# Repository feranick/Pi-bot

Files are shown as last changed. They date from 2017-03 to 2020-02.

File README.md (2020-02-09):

# Pi-bot (piRC)
**Raspberry Pi Remote-controlled/autonomous cars**. Different approaches for control and driving are available:
- Fully autonomous through deep learning neural networks 
- Driving aid, pseudo-automated (tries to avoid obstacles)
- Manual controlled via HTML interface

## Hardware
- robot: RC car with one motor for power, one motor for steering.
- controller: [Raspberry Pi 3 B](https://www.raspberrypi.org/products/raspberry-pi-3-model-b/) or [3 B+](https://www.raspberrypi.org/products/raspberry-pi-3-model-b-plus/). [Raspberry PI zero w](https://www.raspberrypi.org/products/pi-zero-w/)  can be used only with SKLearn and no camera.
- ADC controller: 4 channel 16bit, [ADS1115](http://www.ti.com/lit/ds/symlink/ads1115.pdf) (Op. Voltage: 3.3V)
- Accelerometer: XYZ, [ADXL345](http://www.analog.com/en/products/mems/accelerometers/adxl345.html) (Op. Voltage: 3.3V)
- Stepper motor controller: Adafruit [TB6612](https://learn.adafruit.com/adafruit-tb6612-h-bridge-dc-stepper-motor-driver-breakout/overview), 1.2A DC (Op. Voltage: 3.3V or 5V)
- Sensing the motor status requires a 1.5MOhm resistor to from the power motor leads to the ADS1115. 
- Sonars: 4 [HC-SR04](http://www.micropik.com/PDF/HCSR04.pdf) (left, right, center, back); (Op. Voltage: 5V)
  Warning: the output operating voltage is 5V, while RPi accepts only up to 3.3V, so you need a voltage divider.
- Radar (support is upcoming): 1 microwave Doppler Radar [HB100](https://www.tindie.com/products/limpkin/hb100-doppler-speed-sensor-arduino-compatible/)
- [Raspberry Pi Camera Module](https://www.raspberrypi.org/products/camera-module-v2/)
- Optional: [Google Coral EdgeTPU](https://coral.ai/docs/accelerator/get-started/) for on device efficient inference is supported. Please refer to the product page for installation.

- Deprecated IR sensors:
    - 2 front left side break beam sensors [3mm LEDs](https://www.adafruit.com/products/2167)
    - 1 front [GP2Y0A21YK0F](http://www.sharp-world.com/products/device/lineup/data/pdf/datasheet/gp2y0a21yk_e.pdf) Sharp IR Analog Distance Sensor 10-80cm

## Requirements
Since it uses Python3, it requires the following packages

    sudo apt-get install python3-rpi.gpio python3-dev python3-pip libopenjp2-7 libatlas-base-dev libtiff5 python3-picamera libhdf5-serial-dev libhdf5-dev

You would then need to install two libraries for the ADC (ADS1115) and accelerometer (ADXL345)

    sudo pip3 install adafruit-adxl345 adafruit-ads1x15 Pillow configparser wheel

Machine learing is carried out using Sklearn by default, which needs the following packages:

    sudo pip3 install numpy sklearn 
    
Alternatively and only when used with a Raspberry Pi 3, TensorFlow can be used instead. To install: 

    sudo pip3 install tensorflow tflite-runtime

## Installation
When inside teh folder `Pi-bot/piRC` from the command line:

    python3 setup.bdist_wheel
    sudo pip3 install --upgrade dist/pirc-xxxxxxxx-py3-none-any.whl  
    
You can also run the software directly from the folder (although it is discouraged).
    
- Upon booting Raspbian, the motors may not be responsive due to some GPIO channels not being properly initialized. Use (`piRC/other/pirc_init.py`) to initialize them.

## Usage
### piRC (deep learning neural networks)
All required parameters for ML and for the RC are included into `pirc.ini` which is included in Pi-bot/pirc. If not present, a default file is created upon launching the software.
 
This software (piRC/machine_learning/piRC_ML.py) is designed to accomplish three main tasks
- **Collection mode (CM)** Collect sensor data and save it into what will be a training file. When the software is operated with CM, the user is supposed to operate the RC in fully manual mode (i.e. using the original remote control. You can stop the collection by exiting with CTRL+C. The result is a file (`Training_splrcbxyz.txt`) with sensor readings that are ready for machine training. Examples are provided in `piRC/piRC_ML/Training` (it is strongly recommended to create your own). CM mode runs using this command:

    `pirc -c`

- **Training mode (TM)** Using the training file (for example `Training_splrcbxyz.txt`), a neural network training model is created and saved with the extension `.nnModelC.pkl`. Training can be conducted in the Rpi within the RC car itself, or in any other computer running python and related libraries. This usually is much much faster. TM mode runs using this command:

    `pirc -t <training file>`

- **Running mode (RM)** Once the training is completed, you can run run the inference mode (which uses sensor data acquired in real time to infer steering and power) and ultimately the RC car itself through this command

    `pirc -r Training_splrcbxyz.txt`

Both Classification (default) and Regression can be used.

A few notes on RM:
- If training model is not available, one is created at launch time.
- a bash script is provided (`piRC/machine_learning/syncTraining/syncTFile.sh`) to allow the transfer of the training file to a separate computer, run the training in that computer and retrieve the model for usage in the piRC.
- The training file can be improved while in RM by adding real time sensor data to it (the flag `saveNewTrainingData` needs to be set to True). This is useful as a new training model can be created on the fly (using the bash script as per the previous point). piRC_ML.py can be set to periorically reload (default is 15 seconds, change using `syncTimeLimit`) the training model without relaunching the script (the flag `syncTrainModel` needs to be set to True).
- Two Machine learning methodsare available: using the MultiPerceptron Classifier (`MLPClassifier`, recommended) or Regressor (`MLPRegressor`, highly experimental and not recommended). 
- Two operation modes are available, and can be enabled using the flab `runFullAuto`:
    - Partial Auto: piRC will only respond to the sensor data, but it will no proactively "drive forward" if it has no reason for it. You need to use manual commands to help it. 
    - Full Auto: piRC will proactively drive forward if it has been standing still for a given amount of time. 

### Manual control through web interface (discontinued)
piRC can be controlled using a web interface. Communication between PHP and python is done: 
- via shared file (piRC_file). Auto and manual control take place within the same python script
- via shell (piRC_nofile): Auto control is automated, in the background. Manual control is done via python script when the user 
is calling for an action.

### Additional utilities
- `pirc_init`: Initialize sensors and GPIO ports for full use with remote control.

### Installation (deprecated)
To be working properly, a library file piRC_lib.py needs to be copied inside each of the folders:
- piRC_file
- piRC_nofile
- piRC_ML
- Upon booting Raspbian, the motors may not be responsive due to some GPIO channels not being properly initialized. Use (piRC/other/pirc_init.py) to initialize them.

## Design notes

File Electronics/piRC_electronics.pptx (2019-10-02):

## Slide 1

RPi provides full power

| RCBR | RCBL | | RCBB | RCBF
RCMS - | RCMS+ | | | RCMP- | RCM+

RCB-
RCB+

Motor
Controller

| | | GPIO 14 (12) | GPIO 15 (10) | GPIO 18 (12) | | GPIO 17 (11) | GPIO 27 (13) | GPIO 22 (15)

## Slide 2

RC provides power to Motor controller

| RCBR | RCBL | | RCBB | RCBF
RCMS - | RCMS+ | | | RCMP- | RCM+

RC battery -
RCB-
RCB+
RC battery +

Motor
Controller

| | | GPIO 14 (12) | GPIO 15 (10) | GPIO 18 (12) | | GPIO 17 (11) | GPIO 27 (13) | GPIO 22 (15)

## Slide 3

| GPIO (4) 5V | GPIO (6) GND | | SONAR 5V | SONAR GND

ADC

GPIO (1) 3.3V | GPIO (3) SDA1 | GPIO (5) SCL1 | | GPIO (9) GND

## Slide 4

VCC – RADAR (White)
GND – RADAR (Green)

GPIO8 (24) SPI CE0 (Orange/Yellow)

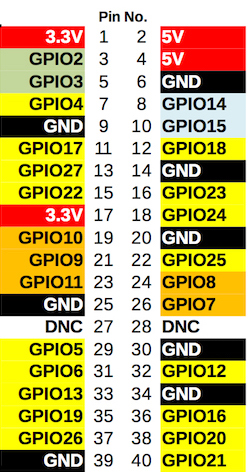
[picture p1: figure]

Example: GPIO 14 (8): GPIO14, pin number 8

RCB = RC Car Main Board
RCMP = RC Car Power Motor
RCMS = RC Car Steer Motor

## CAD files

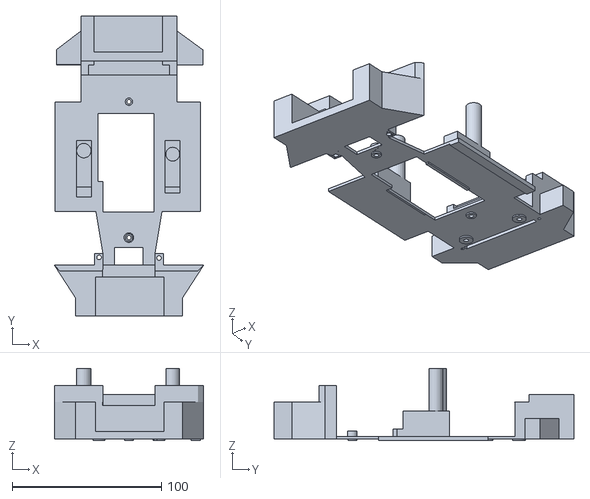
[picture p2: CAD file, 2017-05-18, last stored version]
Sketchup/Chassis_PiRC_11.stl
100.0 x 200.9 x 48.4

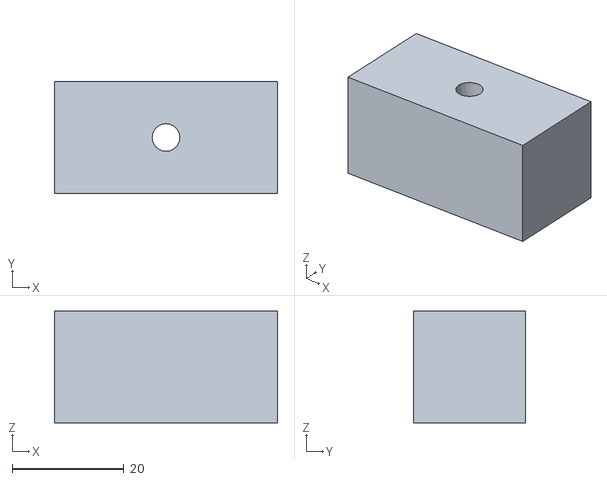
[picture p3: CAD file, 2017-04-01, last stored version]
Sketchup/IR-sensors-holder_2.stl
40.0 x 20.0 x 20.0

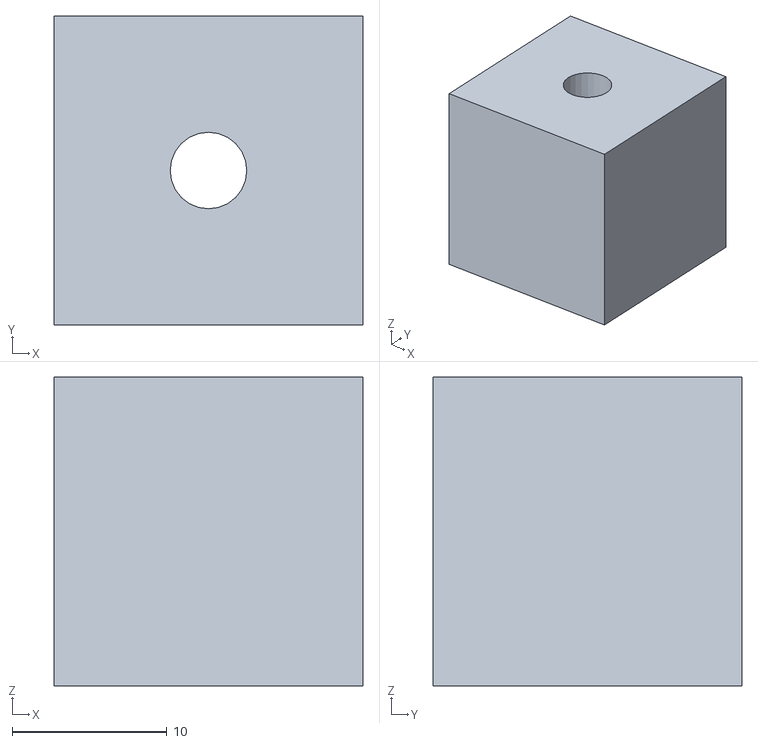
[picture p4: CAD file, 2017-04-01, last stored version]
Sketchup/IR-sensors-holder.stl
20.0 x 20.0 x 20.0

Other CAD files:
Sketchup/Chassis_PiRC_11.skp
Sketchup/IR-sensors-holder.skp
Sketchup/IR-sensors-holder_2.skp

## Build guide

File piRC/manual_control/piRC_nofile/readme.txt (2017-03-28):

pirc_auto.py: controls sensors and object avoidance. It should run in the background.
pirc_manual.py: called from PHP, runs only when needed by user intervention.

In order to have the required permission:

- add the following to the sudoers (sudo visudo):
www-data ALL = NOPASSWD:  /var/www/html/pirc_nofile/piRC_manual.py, /usr/bin/python3

You may be able to speed up launching the python script by compiling it first:

python3 -m compileall ./

In this case, you need to change the proper line in the index.php file.

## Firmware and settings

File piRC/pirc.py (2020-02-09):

#!/usr/bin/env python3
# -*- coding: utf-8 -*-
'''
**********************************************************
* PiRC - Self-driving RC car via Machine Learning
* version: 20200209a
* By: Nicola Ferralis <feranick@hotmail.com>
***********************************************************
'''
print(__doc__)

import numpy as np
import sys, os.path, os, getopt, glob, csv, joblib, configparser
import h5py, pickle
from time import sleep, time
from os.path import exists, splitext
from os import rename
from datetime import datetime, date

from sklearn.neural_network import MLPClassifier, MLPRegressor
from sklearn.preprocessing import StandardScaler
#import libpirc #Comment this out for debug mode.

#***************************************************
# This is needed for installation through pip
#***************************************************
def pirc():
    main()

#************************************
# Parameters
#************************************
class Conf():
    def __init__(self):
        confFileName = "pirc.ini"
        self.configFile = os.getcwd()+"/"+confFileName
        self.conf = configparser.ConfigParser()
        self.conf.optionxform = str
        self.tf_directory = "TF_MLP"
        if os.path.isfile(self.configFile) is False:
            print(" Configuration file: \""+confFileName+"\" does not exist: Creating one.\n")
            self.createConfig()
        self.readConfig(self.configFile)
        
        if self.useCamera == True:
            self.filename = 'Training_splrcbxyzvCam.txt'
            self.camStr = "ON"
        else:
            self.filename = 'Training_splrcbxyzv.txt'
            self.camStr = "OFF"
            
        if self.ML_framework == "SKLearn":
            self.runNN_SK = True
            self.runNN_TF = False
        if self.ML_framework == "TF":
            self.runNN_SK = False
            self.runNN_TF = True
    
        self.scaler = StandardScaler()
        self.scalFileExt = '_scaler.pkl'
        self.mlp = MultiClassReductor()
        
        if not self.debug:
            importModule("libpirc")
            
        self.edgeTPUSharedLib = "libedgetpu.so.1"
            
    def pircDef(self):
        self.conf['Parameters'] = {
            'timeDelay' : .25,
            'runFullAuto' : True,
            'useCamera' : True,
            'nnAlwaysRetrain': True,
            'syncTimeLimit': 20, # time in seconds for NN model synchronization
            'syncTrainModel': False,
            'saveNewTrainingData': True,
            'ML_framework': 'SKLearn',     # Use either: SKLearn (for scikit-learn) or TF (for TensorFlow)
            'useRegressor': False,
            'HL': [270,170,70,10],
            'l2' : 1e-5,
            'epochs' : 200,
            }
            
        self.conf['SKLearn'] = {
            'nnSolver': 'lbfgs',  #Solver for NN lbfgs preferred for small datasets. Alternatives: 'adam' or 'sgd'
            }
            
        self.conf['TF'] = {
            'l_rate' : 0.001,
            'l_rdecay' : 1e-4,
            'drop' : 0,
            'cv_split' : 0.01,
            'fullSizeBatch' : True,
            'batch_size' : 64,
            }
            
        self.conf['System'] = {
            'makeQuantizedTFlite' : False,
            'useTFlitePred' : False,
            'TFliteRuntime' : False,
            'runCoralEdge' : False,
            'debug': False, # do not activate sensors or motors in debug mode
            #'setMaxMem' : False,   # TensorFlow 2.0
            #'maxMem' : 4096,       # TensorFlow 2.0
            }
            

    def readConfig(self,configFile):
        try:
            self.conf.read(configFile)
            self.pircDef = self.conf['Parameters']
            self.sklearnDef = self.conf['SKLearn']
            self.TF = self.conf['TF']
            self.sysDef = self.conf['System']
            
            self.timeDelay = self.conf.getfloat('Parameters','timeDelay')
            self.runFullAuto = self.conf.getboolean('Parameters','runFullAuto')
            self.useCamera = self.conf.getboolean('Parameters','useCamera')
            self.nnAlwaysRetrain = self.conf.getboolean('Parameters','nnAlwaysRetrain')
            self.syncTimeLimit = self.conf.getint('Parameters','syncTimeLimit')
            self.syncTrainModel = self.conf.getboolean('Parameters','syncTrainModel')
            self.saveNewTrainingData = self.conf.getboolean('Parameters','saveNewTrainingData')
            self.ML_framework = self.conf.get('Parameters','ML_framework')
            self.useRegressor = self.conf.getboolean('Parameters','useRegressor')
            self.HL = eval(self.pircDef['HL'])
            self.l2 = self.conf.getfloat('Parameters','l2')
            self.epochs = self.conf.getint('Parameters','epochs')
            
            self.nnSolver = self.conf.get('SKLearn','nnSolver')
            
            self.l_rate = self.conf.getfloat('TF','l_rate')
            self.l_rdecay = self.conf.getfloat('TF','l_rdecay')
            self.drop = self.conf.getfloat('TF','drop')
            self.cv_split = self.conf.getfloat('TF','cv_split')
            self.fullSizeBatch = self.conf.getboolean('TF','fullSizeBatch')
            self.batch_size = self.conf.getint('TF','batch_size')
            
            self.makeQuantizedTFlite = self.conf.getboolean('System','makeQuantizedTFlite')
            self.useTFlitePred = self.conf.getboolean('System','useTFlitePred')
            self.TFliteRuntime = self.conf.getboolean('System','TFliteRuntime')
            self.runCoralEdge = self.conf.getboolean('System','runCoralEdge')
            self.debug = self.conf.getboolean('System','debug')
            
        except:
            print(" Error in reading configuration file. Please check it\n")

    # Create configuration file
    def createConfig(self):
        try:
            self.pircDef()
            with open(self.configFile, 'w') as configfile:
                self.conf.write(configfile)
        except:
            print("Error in creating configuration file")

#**********************************************
''' MultiClassReductor '''
#**********************************************
class MultiClassReductor():
    def __self__(self):
        self.name = name
    
    totalClass = [[-1,-1],[-1,0],[-1,1],[0,-1],[0,0],[0,1],[1,-1],[1,0],[1,1]]
    
    def transform(self,y):
        Cl = np.zeros(y.shape[0])
        for j in range(len(y)):
            Cl[j] = self.totalClass.index(np.array(y[j]).tolist())
        return Cl
    
    def inverse_transform(self,a):
        return self.totalClass[int(a)]
        
    def classes_(self):
        return self.totalClass
        
    def num_classes_(self):
        return len(self.totalClass)


#**********************************************
''' Main '''
#**********************************************
def main():
    params = Conf()
    try:
        opts, args = getopt.getopt(sys.argv[1:], "rtch:", ["run", "train", "collect", "help"])
    except:
        usage()
        sys.exit(2)
    
    if opts == []:
        usage()
        sys.exit(2)

    for o, a in opts:
        if o in ("-r" , "--run"):
            try:
                runAuto(sys.argv[2],params.runFullAuto)
            except:
                exitProg()

        if o in ("-t" , "--train"):
            try:
                runTrain(sys.argv[2])
            except:
                exitProg()

        if o in ("-c" , "--collect"):
            try:
                writeTrainFile()
            except:
                exitProg()

#*************************************************
''' seletMLFramework '''
''' Select and initialize appropriate framework '''
#*************************************************
def selectMLFramework(sensors, Cl, trainFileRoot):
    params = Conf()
    printParams()
    if params.runNN_SK:
        #print(" Using SKLearn")
        model = runNN_SK(sensors, Cl, trainFileRoot)
    if params.runNN_TF:
        if params.TFliteRuntime:
            import tflite_runtime.interpreter as tflite
            # model here is intended as interpreter
            if params.runCoralEdge:
                model = tflite.Interpreter(model_path=os.path.splitext(fileTrainingData(trainFileRoot, True))[0]+'_edgetpu.tflite',
                experimental_delegates=[tflite.load_delegate(params.edgeTPUSharedLib,{})])
            else:
                model = tflite.Interpreter(model_path=os.path.splitext(fileTrainingData(trainFileRoot, True))[0]+'.tflite')
            model.allocate_tensors()
        else:
            import tensorflow as tf
            if params.useTFlitePred:
                # model here is intended as interpreter
                model = tf.lite.Interpreter(model_path=os.path.splitext(fileTrainingData(trainFileRoot, True))[0]+'.tflite')
                model.allocate_tensors()
            else:
                model = tf.keras.models.load_model(fileTrainingData(trainFileRoot, True))

    return model

#*************************************************
''' runAuto '''
''' Use ML models to predict steer and power '''
#*************************************************
def runAuto(trainFile, type):
    params = Conf()
    trainFileRoot = os.path.splitext(trainFile)[0]
    Cl, sensors = readTrainFile(trainFile)
    model = selectMLFramework(sensors, Cl, trainFileRoot)
    scal = pickle.loads(open(trainFileRoot+params.scalFileExt, "rb").read())
    fullStop(False)
    syncTime = time()
    while True:
        if time() - syncTime > params.syncTimeLimit and params.syncTrainModel == True:
            print(" Reloading NN model...")
            model = selectMLFramework(sensors, Cl, trainFileRoot)
            print(" Synchronizing NN model...\n")
            os.system("./syncTFile.sh " + trainFileRoot + " &")
            syncTime = time()
        
        if type == False:
            print(" Running \033[1mPartial Auto\033[0m Mode\n")
            s, p = predictDrive(model, scal, fileTrainingData(trainFileRoot, False))
            drive(s,p)
            sleep(params.timeDelay)
        else:
            print(" Running \033[1mFull Auto\033[0m Mode\n")
            dt=0
            t1=time()
            while dt < 0.5:
                s, p = predictDrive(model, scal, fileTrainingData(trainFileRoot, False))
                if p != 0:
                    dt = 0
                    drive(s,p)
                else:
                    dt = time() - t1
                sleep(params.timeDelay)
            drive(0, 1)
            sleep(0.5)
            drive(0, 0)

#*************************************************
''' runTrain '''
''' Use ML models to predict steer and power '''
#*************************************************
def runTrain(trainFile):
    params = Conf()
    trainFileRoot = os.path.splitext(trainFile)[0]
    Cl, sensors = readTrainFile(trainFile)
    params.nnAlwaysRetrain = True
    printParams()
    if params.runNN_SK:
        #print(" Using SKlearn")
        runNN_SK(sensors, Cl, trainFileRoot)
    if params.runNN_TF:
        #print(" Using TensorFlow")
        runNN_TF(sensors, Cl, trainFileRoot)

#*************************************************
''' write training file from sensors '''
#*************************************************
def writeTrainFile():
    params = Conf()
    while True:
        data = libpirc.readAllSensors(params.useCamera)
        print(' S={0:.0f}, P={1:.0f}, L={2:.0f}, R={3:.0f}, C={4:.0f}, B={5:.0f}, X={6:.3f}, Y={7:.3f}, Z={8:.3f}, V={9:.2f}, Cam={10:s}'.format(\
        data[0],data[1],data[2],data[3],data[4],data[5],data[6],data[7],data[8],data[9],params.camStr))
        with open(params.filename, "ab") as sum_file:
            np.savetxt(sum_file, [data], fmt="%.2f", delimiter=' ', newline='\n')

#*************************************************
''' read Train File '''
#*************************************************
def readTrainFile(trainFile):
    params = Conf()
    try:
        with open(trainFile, 'r') as f:
            M = np.loadtxt(f, unpack =False)
    except:
        print('\033[1m' + ' Training file not found \n' + '\033[0m')
        return

    steer = M[:,0]
    power = M[:,1]
    Cl = M[:,[0,1]]
    
    sensors = np.delete(M,np.s_[0:2],1)
    return Cl, sensors

#********************************************************************************
''' Run Neural Network '''
#********************************************************************************
def runNN_SK(sensors, Cl, Root):
    params = Conf()
    nnTrainedData = fileTrainingData(Root, True)
    print("\n Training file:", nnTrainedData)

    try:
        if params.nnAlwaysRetrain == False:
            with open(nnTrainedData):
                print(' Opening NN training model...\n')
                model = joblib.load(nnTrainedData)
            print("\n Done. Training model loaded")
        else:
            raise ValueError("\n Force NN retraining.")
    except:
        #**********************************************
        ''' Retrain data if not available'''
        #**********************************************
        print("\n Retraining NN model...")
        
        params.scaler.fit(sensors)
        sensors = params.scaler.transform(sensors)
        
        with open(Root+params.scalFileExt, 'ab') as g:
            g.write(pickle.dumps(params.scaler))
        print("\n Scaling model saved in: ",nnTrainedData)
            
        
        if params.useRegressor is False:
            Y = params.mlp.transform(Cl)
            #print(params.mlp.classes_())
        else:
            Y = Cl
        
        if params.useRegressor is False:
            model = MLPClassifier(solver=params.nnSolver, hidden_layer_sizes=params.HL, random_state=1,
                alpha = params.l2, max_iter = params.epochs)
        else:
            model = MLPRegressor(solver=params.nnSolver, hidden_layer_sizes=params.HL, random_state=9,
                alpha = params.l2, max_iter = params.epochs)
        model.fit(sensors, Y)
        joblib.dump(model, nnTrainedData)
    
    print("\n Done. Training model saved in: ",nnTrainedData,"\n")

    return model

#********************************************************************************
''' Run Neural Network '''
#********************************************************************************
def runNN_TF(sensors, Cl, Root):
    params = Conf()
    nnTrainedData = fileTrainingData(Root, True)
    print("\n Training file:", nnTrainedData)

    try:
        import tensorflow as tf
        from pkg_resources import parse_version
        
        if parse_version(tf.version.VERSION) < parse_version('2.0.0'):
            tf.compat.v1.enable_eager_execution()
        
        import tensorflow.keras as keras  #tf.keras
        
        if params.nnAlwaysRetrain == False:
            print("\n Opening NN training model...")
            model = keras.models.load_model(nnTrainedData)
            print("\n Done. Training model loaded\n")
        else:
            raise ValueError("\n Force NN retraining.")
    except:
        #**********************************************
        ''' Retrain data if not available'''
        #**********************************************
        print("\n Retraining NN model...")
        #tf.compat.v1.Session(config=conf)
        
        params.scaler.fit(sensors)
        sensors = params.scaler.transform(sensors)
        with open(Root+params.scalFileExt, 'ab') as g:
            g.write(pickle.dumps(params.scaler))
        
        if params.useRegressor is False:
            Y = params.mlp.transform(Cl)
            Y = keras.utils.to_categorical(Y, num_classes=params.mlp.num_classes_())
        else:
            Y = Cl
            
        if params.fullSizeBatch == True:
            params.batch_size = sensors.shape[0]
                    
        optim = keras.optimizers.Adam(lr=params.l_rate, beta_1=0.9,
        beta_2=0.999, epsilon=1e-08, decay=params.l_rdecay,
        amsgrad=False)
        
        #************************************
        ### Build model
        #************************************
        model = keras.models.Sequential()
        for i in range(len(params.HL)):
            model.add(keras.layers.Dense(params.HL[i],
                activation = 'relu',
                input_dim=sensors.shape[1],
                kernel_regularizer=keras.regularizers.l2(params.l2)))
            model.add(keras.layers.Dropout(params.drop))
        
        if params.useRegressor:
            model.add(keras.layers.Dense(2))
            model.compile(loss='mse',
            optimizer=optim,
            metrics=['mae'])
        else:
            model.add(keras.layers.Dense(params.mlp.num_classes_(), activation = 'softmax'))
            model.compile(loss='categorical_crossentropy',
                optimizer=optim,
                metrics=['accuracy'])
    
        tbLog = keras.callbacks.TensorBoard(log_dir=params.tf_directory,
                write_graph=True, write_images=True)
        tbLogs = [tbLog]
                
        log = model.fit(sensors, Y,
            epochs=params.epochs,
            batch_size=params.batch_size,
            callbacks = tbLogs,
            verbose=2)
                
        model.save(nnTrainedData)
        
        if params.makeQuantizedTFlite:
            makeQuantizedTFmodel(sensors, model, nnTrainedData)
        
        print("\n Training with TensorFlow v.",tf.version.VERSION)
        print("\n Done. Training model saved in: ",nnTrainedData,"\n")

    return model

#*************************************************
''' Predict drive pattern '''
#*************************************************
def predictDrive(model, scal, root):
    params = Conf()
    np.set_printoptions(suppress=True)
    sp = [0,0]
    if params.debug is True:
        data = [0,0,254.36,36.73,132.25,124.67,
                0,0,0,0,149,151,147,141,139,99,87,82,98,101,181,157,
                179,116,136,108,91,83,90,76,124,141,174,93,131,90,86,
                85,81,63,158,140,138,88,126,60,74,78,74,59,183,191,158,
                147,143,81,83,86,81,63,119,129,144,181,158,163,115,93,
                85,69,28,175,171,85,199,209,106,85,79,99,9,183,176,124,
                218,168,85,106,78,109,145,207,149,129,233,171,81,101,85,
                84,196,205,123,134,208,138,67,96,79,103]
    else:
        data = libpirc.readAllSensors(params.useCamera)

    print(' S={0:.0f}, P={1:.0f}, L={2:.0f}, R={3:.0f}, C={4:.0f}, B={5:.0f}, X={6:.3f}, Y={7:.3f}, Z={8:.3f}, V={9:.2f}'.format(\
            data[0],data[1],data[2],data[3],data[4],data[5],data[6],data[7],data[8],data[9]))

    nowsensors = np.array([[round(data[2],0),round(data[3],0),round(data[4],0),round(data[5],0),
        round(data[6],3),round(data[7],3),round(data[8],3),round(data[9],2)]])

    if params.useCamera == True:
        nowsensors = np.append(nowsensors, data[10:]).reshape(1,-1)

    if params.useRegressor:
        if params.ML_framework == "SKLearn":
            sp = model.predict(nowsensors)[0]
        if params.ML_framework == "TF":
            if params.useTFlitePred:
                sp = getPredictions(nowsensors, model)
            else:
                sp = model.predict(R).flatten()[0]
        
        print('\033[1m' + ' Predicted regression = ( S=',str(sp[0]),', P=',str(sp[1]),')')
        for k in range(2):
            if sp[k] >= 1:
                sp[k] = 1
            elif sp[k] <= -1:
                sp[k] = -1
            else:
                sp[k] = 0
        print('\033[1m' + ' Predicted regression = ( S=',str(sp[0]),', P=',str(sp[1]),') Normalized\n')
    else:
        nowsensors = scal.transform(nowsensors)
        try:
            if params.ML_framework == "SKLearn":
                predictions = model.predict(nowsensors)
                sp = params.mlp.inverse_transform(predictions[0])
                prob = model.predict_proba(nowsensors)[0].tolist()
                predProb = round(100*max(prob),2)
        
            if params.ML_framework == "TF":
                if params.useTFlitePred:
                    predictions = getPredictions(nowsensors, model)
                    predProb = round(100*predictions[0][np.argmax(predictions)]/255,2)
                else:
                    predictions = model.predict(nowsensors, verbose=0)
                    predProb = round(100*predictions[0][np.argmax(predictions)],2)
                #pred_class = np.argmax(predictions)
                sp = params.mlp.inverse_transform(np.argmax(predictions))
            
        except:
            print(" FAIL")
            sp = [0,0]
            predProb = 0
                    
        print('\033[1m' + ' Predicted classification = ( S=',str(sp[0]),', P=',str(sp[1]),') (prob = ' + str(predProb) + '%)\033[0m\n')
        #print(' (prob = ' + str(predProb) + '%)\033[0m\n')
        
    if params.saveNewTrainingData is True:
        with open(params.filename, "a") as sum_file:
            np.savetxt(sum_file, [data], fmt="%.2f", delimiter=' ', newline='\n')

    return sp[0], sp[1]
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

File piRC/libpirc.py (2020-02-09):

#!/usr/bin/env python3
# -*- coding: utf-8 -*-
'''
**********************************************************
*
* libpirc
* version: 20200209a
*
* By: Nicola Ferralis <feranick@hotmail.com>
*
***********************************************************
'''

import RPi.GPIO as GPIO
from time import sleep, time
import sys
import random as rd
import Adafruit_ADXL345  # Accelerometer ADXL345
import Adafruit_ADS1x15  # ADC ADS1115
from PIL import Image
import picamera
import numpy as np

#************************************
''' GPIO definitions '''
#************************************

TRIG = [35,31,29,38]
ECHO = [37,33,32,40]

AIN1 = 11
AIN2 = 13
PWNA = 15
BIN1 = 8
BIN2 = 10
PWNB = 12

RADIN = 24

GPIO.setwarnings(False)
GPIO.setmode(GPIO.BOARD)

for i in range(len(ECHO)):
    GPIO.setup(TRIG[i],GPIO.OUT)
    GPIO.setup(ECHO[i],GPIO.IN)

GPIO.setup(AIN1,GPIO.OUT)   #AIN1 motor input A
GPIO.setup(AIN2,GPIO.OUT)   #AIN2 motor input B
GPIO.setup(PWNA,GPIO.OUT)   #PWNA motor input B (power) - analog
GPIO.setup(BIN1,GPIO.OUT)   #BIN1 motor input A
GPIO.setup(BIN2,GPIO.OUT)   #BIN2 motor input B
GPIO.setup(PWNB,GPIO.OUT)   #PWNA motor input B (power) - analog

GPIO.setup(RADIN, GPIO.IN)  #Radar

#************************************
''' General definitions '''
#************************************
SCALE_MULTIPLIER = 0.004
EARTH_GRAVITY_MS2  = 9.80665

timeSleepSensor = 0.1
timeTransient0 = 0.05
timeTransient1 = 0.2
timeTransient2 = 0.75
timeTransient3 = 1
minDistanceL = 15
minDistanceR = 15
minDistanceC = 15
minDistanceB = 10

filename = 'Training_splrcbxyz.txt'

maxSonarRange = 1000 # max set distance in cm

radNumCycles = 3 # number of cycles to average for radar
radTimeout = 100 #ms
radMinSpeed = 0.22

img_size = (320, 320)
resized_size = (10,10)

#************************************
''' Control Motors'''
#************************************
def runMotor(motor, state):
    if motor == 1:  # motor for powering vehicle
        in1 = AIN1
        in2 = AIN2
        pwn = PWNA
    
    elif motor == 0:    # motor for steering
        in1 = BIN1
        in2 = BIN2
        pwn = PWNB
    
    if state == -1:
        GPIO.output(in1,0)
        GPIO.output(in2,1)
    if state == 0:
        GPIO.output(in1,0)
        GPIO.output(in2,0)
    if state == 1:
        GPIO.output(in1,1)
        GPIO.output(in2,0)
    #full power
    GPIO.output(pwn, 255)

#************************************
''' Read sonars '''
#************************************
def readAllSonars(TRIG, ECHO):
    from multiprocessing.dummy import Pool as ThreadPool
    pool = ThreadPool(len(ECHO))
    distances = pool.starmap(readSonar, zip(TRIG,ECHO))
    pool.close()
    pool.join()
    return distances[0], distances[1], distances[2], distances[3]

def readSonar(TRIG,ECHO):
    pulse_start = 0.0
    pulse_end = 0.0
    initTime = time()
    
    GPIO.output(TRIG, False)
    sleep(0.001)
    GPIO.output(TRIG, True)
    sleep(0.0002)
    GPIO.output(TRIG, False)
    
    while GPIO.input(ECHO)==0:
        pulse_start = time()
    
    while GPIO.input(ECHO)==1:
        pulse_end = time()
        if time() - initTime > 0.5:
            break
    pulse_duration = pulse_end - pulse_start
    distance = pulse_duration * 17150
    distance = round(distance, 2)
    if distance > maxSonarRange:
        distance = maxSonarRange
    return distance

#************************************
''' Read Accelerometer '''
#************************************
def readAccel(isG):
    accel = Adafruit_ADXL345.ADXL345(address=0x53,busnum=1)
    accel.set_range(Adafruit_ADXL345.ADXL345_RANGE_2_G)
    x, y, z = [r*SCALE_MULTIPLIER for r in accel.read()]
    if isG is False:
        (x, y, z) = tuple(r*EARTH_GRAVITY_MS2 for r in (x,y,z))
    return x, y, z

#************************************
''' Read Status Motors '''
#************************************
def statMotors():
    adc = Adafruit_ADS1x15.ADS1115(address=0x48,busnum=1)
    GAIN = 1
    FACTOR = 5/32000 # using a 1.5MOhm
    s1 = (adc.read_adc(0, gain=GAIN, data_rate=128)-adc.read_adc(1, gain=GAIN, data_rate=128))*FACTOR
    p1 = (adc.read_adc(3, gain=GAIN, data_rate=128)-adc.read_adc(2, gain=GAIN, data_rate=128))*FACTOR
    if s1 > 2:
        s = 1
    elif s1<-2:
        s = -1
    else:
        s = 0
    if p1 > 2:
        p = 1
    elif p1<-2:
        p = -1
    else:
        p = 0
    return s, p

#************************************
''' Read Speed via Radar Doppler '''
#************************************
def getSpeedRadar():
   GPIO.wait_for_edge(RADIN, GPIO.FALLING, timeout = radTimeout)
   start = time()
   for impulse_count in range(radNumCycles):
      GPIO.wait_for_edge(RADIN, GPIO.FALLING, timeout = radTimeout)
   duration = time() - start       # seconds to run loop
   frequency = radNumCycles / duration    # in Hz
   speed = frequency * float(0.44704) / float(31.36)     # Hz to km/h from sensor datasheet
   if speed < radMinSpeed:
      speed = 0
   return speed

#************************************
''' Camera methods '''
#************************************
class Camera():
    def __init__(self, parent=None):
        #print("Initializing camera")
        self.cam = picamera.PiCamera()
        self.cam.resolution = img_size
        self.cam.vflip = True
        self.cam.hflip = True

    def getImage(self):
        output = np.empty((img_size[0], img_size[1],3), dtype=np.uint8)
        self.cam.capture(output, 'rgb')
        img = Image.fromarray(output).convert('L')
        img_resized = img.resize(resized_size, Image.ANTIALIAS)
        data = np.asarray( img_resized, dtype="int32" ).flatten()
        #print(data)
        return data

    def saveImage(self, npdata, outfilename ) :
        self.img = Image.fromarray( np.asarray( np.clip(npdata,0,255), dtype="uint8"), "L" )
        self.img.save( outfilename )

cam = Camera()

#************************************
''' Read All sensors '''
#************************************
def readAllSensors(useCamera):
    l,r,c,b = readAllSonars(TRIG, ECHO)
    x,y,z = readAccel(True)
    s,p = statMotors()
    v = getSpeedRadar()
    data = np.asarray((s,p,l,r,c,b,x,y,z,v))
    if useCamera == True:
        img = cam.getImage()
        data = np.append(data, img)
        #print(data)
    return data

#************************************
''' Full Stop '''
#************************************
def fullStop(end):
    runMotor(0,0)
    runMotor(1,0)
    if end is True:
        print('\n FULL STOP - Ending\n')
        GPIO.cleanup()
    else:
        print('\n FULL STOP - Starting...\n')
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

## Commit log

2017-03-27 Split steering and power control.
2017-03-30 Don't run motor at all time yet. stop at 1 sec.
2017-03-31 Lots of bug fixes
    Autodriving, sensors, etc.
    [piRC.py]
2017-03-31 Fixed random generation of direction
    [piRC.py]
2017-03-31 Steer straight if sensors are clear.
2017-04-01 Rename sensor tags for clarity.
2017-04-01 Prepare support for central distance IR sensor
2017-04-01 Further support for central sensor.
2017-04-01 Added untested driver with support for front deep detection.
2017-04-01 Added Sketchup and STL files for sensor support and bumper.
    [IR-sensors-holder.skp, IR-sensors-holder.stl, IR-sensors-holder_2.skp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]
2017-04-04 Obstacle detection is now part of the library. Two versions available.
    2: for two sensors (to be deprecated).
    3: for 3 sensors
2017-04-24 Branched version based on ir sensors
2017-04-24 Added i2c test files.
2017-04-24 First implementation of distance detection trhough sonars.
2017-04-24 Bug fixes on sonars reading.
    [piRC_gpio.py, piRC_lib.py]
2017-04-24 Added test file for testing new sonar lib.
2017-04-24 Updated sonar based obstacle avoidance.
    [piRC_lib.py]
2017-04-24 Added test file for accelerometer - ADXL345
2017-04-25 Updated main files for sonars.
2017-04-25 Added support for back sensor.
2017-04-25 Added accelerometer support in lib.
2017-04-25 Apply GPIO.cleanup() correctly at the end of the program
    [piRC.py, piRC_lib.py]
2017-04-25 Updated voltage requirements for sub-boards.
2017-04-26 Bug fixes on ML
    [piRC_ML.py]
2017-04-26 New algorithm for managing recording of steer and power.
2017-04-27 Bug fixes and improvements
    [piRC_ML.py]
2017-04-27 Update GPIO for sonars
2017-04-27 Bug fixes. Add new data to traiinng file when running.
    [piRC_ML.py, piRC_lib.py]
2017-04-28 Updated pins in sonar_distance
2017-04-28 Bug fixes on piRC_file
    [piRC.py]
2017-04-28 Fixed bug on steer status
    [piRC_lib.py]
2017-04-29 Rewritten scheme for taking nowsensors. Bug Fixes.
    [piRC_ML.py]
2017-04-29 Fixed normalization of regression results.
    [piRC_ML.py]
2017-05-01 Implemented initial proactive driving
    This to prevent PiRC to stand still. It should be moving when being stopped for a while.
    Experimental.
    [piRC_ML.py]
2017-05-02 Reordered pins for sonars.
2017-05-03 Experimental: Place timeout on ECHO for sonars.
2017-05-09 Added GPIO definitions for testing i2c files
    Without, the step-motor-controller doesn't play nice with the ADC.
    [test5.py]
2017-05-09 Sonar testing utility takes argument for each sonar
    1: front, 2: left, 3: right, 4: back.
    ,
2017-05-09 Fix incorrect indents in sonar-testing.
    [sonar_distance.py]
2017-05-10 Added initialization script for GPIO ports
    When first powered the RPI confuses the built-in manual controls.
    This script defines the proper I/O to avoid conflicts.
    [piRC_init.py]
2017-05-10 Rewritten sonar detection
2017-05-10 Visualize sensor status during running in ML mode.
2017-05-11 Fixed initialization of binarizer and sp variables
    [piRC_ML.py]
2017-05-12 Added max limit on sonars distance.
2017-05-12 Added test script for motors.
2017-05-12 Use more realistic debug sensor value.
2017-05-12 Debug mode does no longer need to be run in pirc
    It can be run in any computer.
    [piRC_ML.py]
2017-05-12 Prevent race between arguments in command line
    [piRC_ML.py]
2017-05-12 Fixed ssue in running with MLPRegressor
    [piRC_ML.py]
2017-05-18 Added track training file
2017-05-18 Added Sketchup design of the car frame
    [Chassis_PiRC_11.skp, Chassis_PiRC_11.stl]
2017-05-18 Compress Sketchup files
    [Chassis_PiRC_11.skp, Chassis_PiRC_11.stl, IR-sensors-holder.skp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]
2017-05-31 Moved training files in dedicated folder.
    This is in preparation for the new training files that include velocity.
2017-05-31 Archiving copy of stable pirc_ML and piRC_lib
    In preparation of new version reading velocity via radar.
2017-05-31 Added testing utility for Doppler radar
    HB100 Doppler Speed Sensor
2018-01-03 Fix minor bug on radar.py
    [radar.py]
2018-01-03 Updated piRC_lib.py to add support for sonar
    Also updated radar.py to display speed in m/s
2018-01-12 New camera reading for fast acquisition
2018-01-12 Initial implementation of camera acquisition
2018-01-12 Several bug fixes and performance improvements on the camera integration
    [piRC_ML.py, piRC_lib.py]
2018-01-12 Disable camera by default
2018-01-12 Very initial implementation of camera data inclusion
2018-01-12 Initial transition of camera data inclusion as np.array
2018-01-12 Camera acqusition and processing is now fully activated
2019-09-24 Adapt sonar reading to actual hardware configuration
2019-09-25 Refactored configration parameters and bug fixes
    [libpirc.py, pirc.py]
2019-09-25 Bug fixes and improvements on TF
    [libpirc.py, pirc.py]
2019-09-25 Bug fixes and simplification
    [pirc.py]
2019-09-25 Fixed issue during TF regression
    [pirc.py]
2019-10-02 Added electronics schematics for piRC
2019-10-03 Updated default sensor orders
2019-10-04 Updated default config. Bug fixes on TF
    [libpirc.py, pirc.py]
2019-10-22 Bug fixes and improvements in UI
    [libpirc.py, pirc.py]
2019-10-23 Bug fixes on operating in debi
    [libpirc.py, pirc.py]
2019-10-24 Add warning when prediction fails
    [pirc.py]
2019-10-24 Fixed bug in predction probabilities.
    [pirc.py]
